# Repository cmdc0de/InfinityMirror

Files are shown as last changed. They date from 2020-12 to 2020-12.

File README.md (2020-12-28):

# InfinityMirror

## Materials you'll need:
* [Acrylic Mirror](https://www.amazon.com/Acrylic-Mirror-Sheet-Laser-Creations/dp/B01MXE417D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)
* [Acrylic see through Mirror](https://www.amazon.com/0-04-Acrylic-See-Through-Mirror-Transparent/dp/B07XTRC7F1?th=1)
* [ABS](https://www.raise3d.com/filaments/abs/) - I have a Raise 3D printer
* [22 Gauge Wire](https://www.amazon.com/gp/product/B00B4ZRPEY/ref=ppx_yo_dt_b_asin_title_o05_s02?ie=UTF8&psc=1)
* Solder 
* [Solder paste](https://www.amazon.com/Solder-Bi57-6-No-Clean-Lead-Free-Temperature/dp/B0195V1QEI/) - LOW TEMP solder
* Hot Glue
* [rechargable battery](https://www.amazon.com/Capacity-Rechargeable-Batteries-Flashlights-Headlamps/dp/B08MQDFQD4/)

## Equipment you'll need:
* 3d Printer
* laser cutter
* Solder Iron
* Hot Glue Gun

## Instructions
1. Mill/Etch/Order 20x Single-APA102c-breakout boards
2. Mill/Etch/Order 1x STM32G031J6M6 board
3. 3D Print: 3dprint/Base.stl, 3dprint/Base-bottom.stl, 3dprint/lid.stl, and 3dprint/octagon.stl
4. laser cut: laser-cutter/octagon v13.dxf 
5. Add components to the STM32G031J6M6 board.
6. Add componetns to 20x Single-APA102c-breakout boards - if you use an IR Oven make sure you use low temp solder!!! APA102c HATE 250 degress C!
7. Cut wires to length and connect all 20 Single-APA102c-breakout boards
8. Hot Glue apa102c breakouts into wholes of octogan - use a wire length of 3-4 inches for the first apa102c so you can feed it through the hole in the octagon and through the hole in the base to connect it to the STM32G031J6M6 baord.
9. Place acrylic mirror into bottom (it should fit via friction but I used a bit of CA glue as well).
10. place see through (2-way) mirror in the lid, again should fit via friction but I used a bit of CA glue as well.
11. Snap the lid on the octagon
12. Connect wires to STM32G031J6M6
13. Program the STM32G031J6M6 via J-LInk or ST-LInk connector and [STM32CubeIDE](https://www.st.com/en/development-tools/stm32cubeide.html)
  1. Open project in firmware directory
  2. compile and program 
14. Hot Glue board to bottom-lid such that the STM32G031J6M6 board fits in the whole in the base.
15. Connect a rechargable 3.7-5V battery to the screw terminals 
16. Connect Base-bottom to base

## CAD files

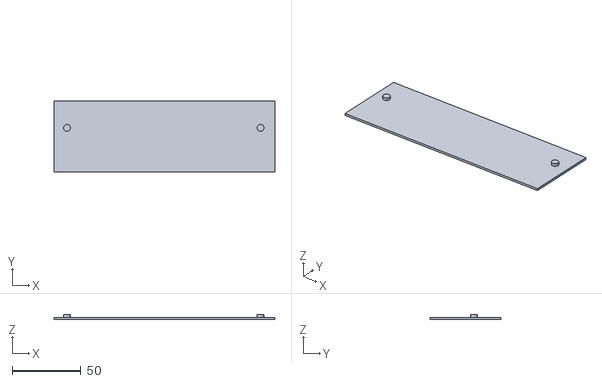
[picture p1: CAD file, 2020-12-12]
3d-print/base-bottom.stl
161.0 x 52.0 x 3.50

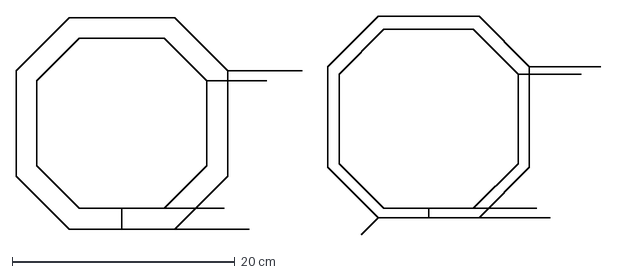
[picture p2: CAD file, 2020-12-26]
laser-cutter/octagon v13.dxf
52.4 x 19.6 cm

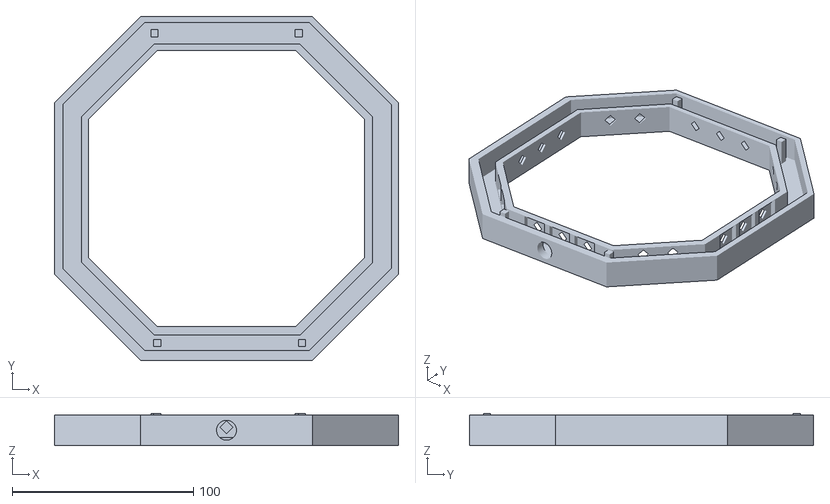
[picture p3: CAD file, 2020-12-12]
3d-print/octagon.stl
189.6 x 189.6 x 17.7

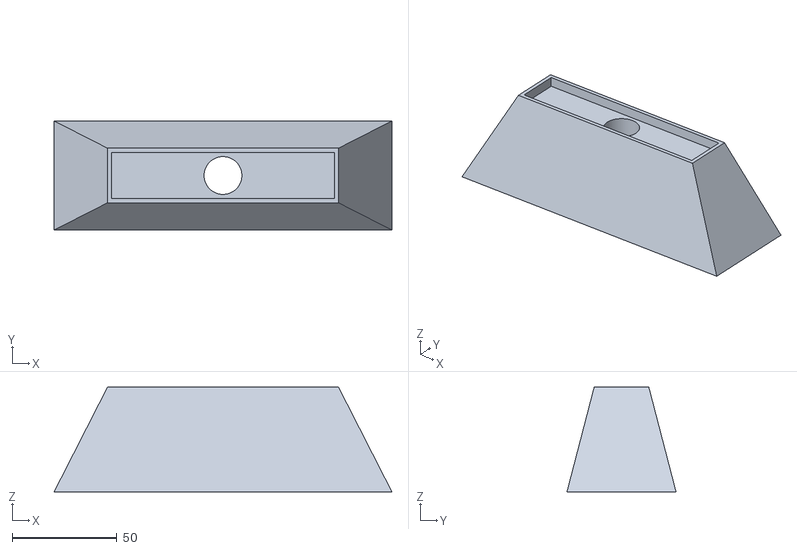
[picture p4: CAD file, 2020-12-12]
3d-print/base.stl
161.0 x 52.0 x 50.0

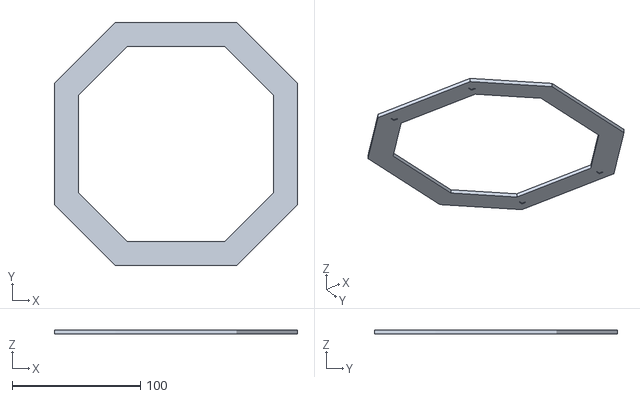
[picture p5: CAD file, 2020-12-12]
3d-print/lid.stl
189.6 x 189.6 x 3.10

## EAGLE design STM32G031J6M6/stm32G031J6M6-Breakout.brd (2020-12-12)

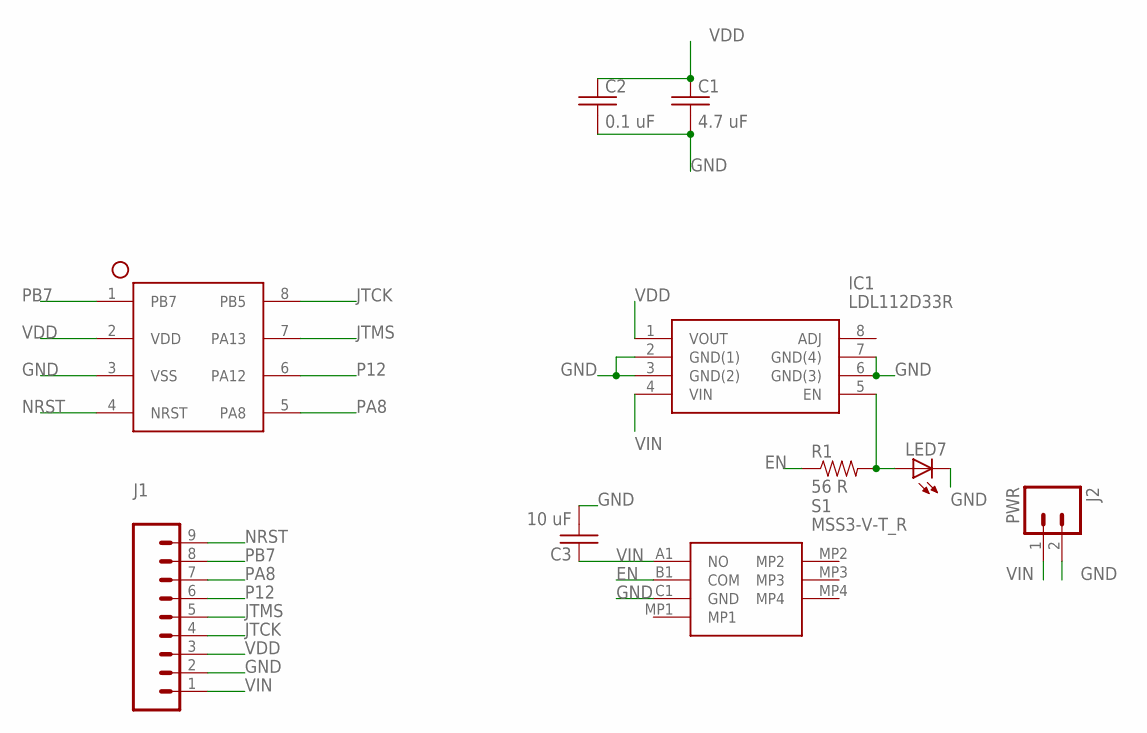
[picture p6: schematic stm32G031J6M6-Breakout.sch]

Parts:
C1: 4.7 uF; C0805K
C2: 0.1 uF; C0805K
C3: 10 uF; C0805K
IC1: LDL112D33R; SOIC127P600X175-8N
J1: M09LONGPADS; 1X09_LONGPADS
J2: PWR; SCREWTERMINAL-5MM-2
LED7: LED1206; LED-1206
R1: 56 R; 1206
S1: MSS3-V-T_R; MSS3VTR
U$1: STM32G031S08N; SOIC127P600X175-8N

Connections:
EN: R1.1, S1.B1 (COM)
GND: C1.2, C2.2, C3.2, IC1.2 (GND(1)), IC1.3 (GND(2)), IC1.6 (GND(3)), IC1.7 (GND(4)), J1.2, J2.2, LED7.C, S1.C1 (GND), U$1.3 (VSS)
JTCK: J1.4, U$1.8 (PB5)
JTMS: J1.5, U$1.7 (PA13)
unnamed: IC1.5 (EN), LED7.A, R1.2
NRST: J1.9, U$1.4 (NRST)
P12: J1.6, U$1.6 (PA12)
PA8: J1.7, U$1.5 (PA8)
PB7: J1.8, U$1.1 (PB7)
VDD: C1.1, C2.1, IC1.1 (VOUT), J1.3, U$1.2 (VDD)
VIN: C3.1, IC1.4 (VIN), J1.1, J2.1, S1.A1 (NO)

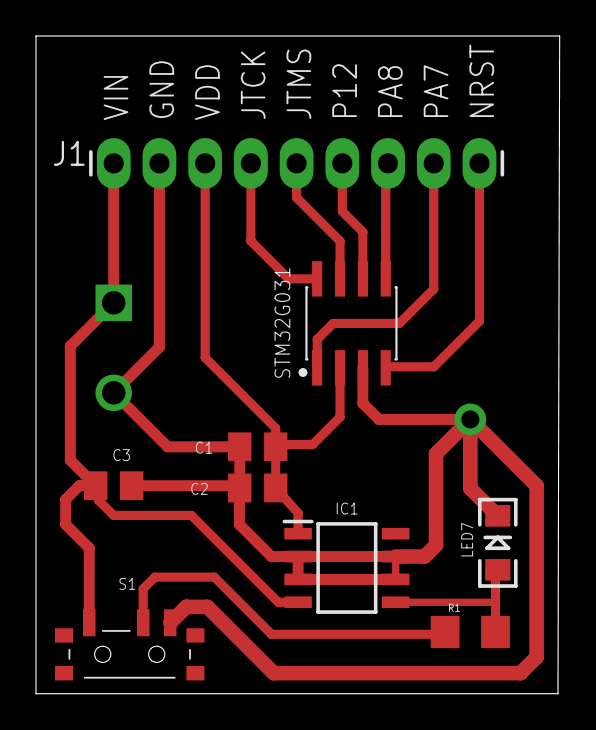
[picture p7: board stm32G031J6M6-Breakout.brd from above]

Board: 2 copper layers, 29.1 x 36.5 mm, 10 parts (1 on the bottom side), 11 nets.

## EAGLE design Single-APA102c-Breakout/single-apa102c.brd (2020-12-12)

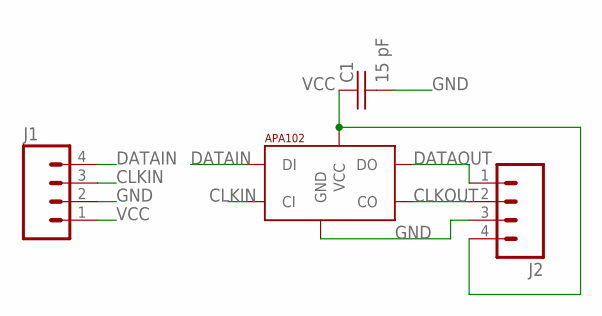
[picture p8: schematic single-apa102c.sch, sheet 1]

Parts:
C1: 15 pF; C0805K
J1, J2: M04PTH; 1X04
U$1: APA1025050; APA102_5050

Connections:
CLKIN: J1.3, U$1.5 (CI)
CLKOUT: J2.2, U$1.2 (CO)
DATAIN: J1.4, U$1.4 (DI)
DATAOUT: J2.1, U$1.3 (DO)
GND: C1.2, J1.2, J2.3, U$1.6 (GND)
VCC: C1.1, J1.1, J2.4, U$1.1 (VCC)

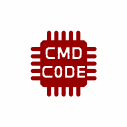
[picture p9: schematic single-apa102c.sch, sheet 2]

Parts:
U$2: CMD_C0DE_LOGOCMD_CODE_LOGO_SILK; CMD_C0DE_LOGO_SILK

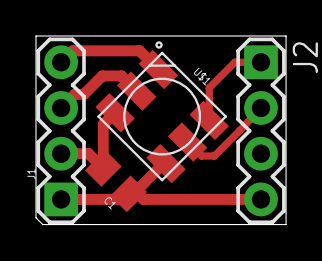
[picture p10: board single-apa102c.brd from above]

Board: 2 copper layers, 13.9 x 10.5 mm, 5 parts (1 on the bottom side), 6 nets.

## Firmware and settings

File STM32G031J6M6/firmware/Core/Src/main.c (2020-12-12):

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
/* Includes ------------------------------------------------------------------*/
#include "main.h"
#include "dma.h"
#include "spi.h"
#include "gpio.h"


void SystemClock_Config(void);
/**
  * @brief  The application entry point.
  * @retval int
  */
int main(void)
{
  /* MCU Configuration--------------------------------------------------------*/

  /* Reset of all peripherals, Initializes the Flash interface and the Systick. */
  HAL_Init();

  /* Configure the system clock */
  SystemClock_Config();

  /* Initialize all configured peripherals */
  MX_GPIO_Init();
  MX_DMA_Init();
  MX_SPI1_Init();
  /* USER CODE BEGIN 2 */
  static const uint32_t STORAGE=FLASH_PAGE_NB-1;
  uint32_t *startStorageAddress = STORAGE*FLASH_PAGE_SIZE+FLASH_BASE;
  if(((*startStorageAddress)&0xFF)==0xFF) {
	  if(HAL_OK!=HAL_FLASH_Program(FLASH_TYPEPROGRAM_DOUBLEWORD, startStorageAddress, 0x0000000000000000)) {
  			//blink LED
	  }
  } else if (((*startStorageAddress)&0xFF)==0x00) {
	  //search for first 0xFF, then move back 8 bytes and read value
  } else {
	  //error
  }
  //HAL_FLASH_Program(TypeProgram, Address, Data)

  /* USER CODE END 2 */

  /* Infinite loop */
  /* USER CODE BEGIN WHILE */
  while (1)
  {
    /* USER CODE END WHILE */

    /* USER CODE BEGIN 3 */
  }
  /* USER CODE END 3 */
}

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


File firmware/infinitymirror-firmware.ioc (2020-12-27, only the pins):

Mcu.UserName=STM32G031J6Mx
PA1.GPIO_Label=LED_CLK
PA1.Signal=SPI1_SCK
PA13.Signal=SYS_SWDIO
PA14-BOOT0.Signal=SYS_SWCLK
PB0.GPIO_Label=CHANGE_DANCE
PB0.Signal=GPIO_Input

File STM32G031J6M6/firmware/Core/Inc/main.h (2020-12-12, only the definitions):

#define BUTTON_IRQ_Pin GPIO_PIN_7
#define BUTTON_IRQ_GPIO_Port GPIOB
#define BUTTON_IRQ_EXTI_IRQn EXTI4_15_IRQn
#define INDICATOR_LED_Pin GPIO_PIN_11
#define INDICATOR_LED_GPIO_Port GPIOA

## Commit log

2020-11-21 initial checkin
    [single-apa102c.brd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]
2020-12-12 base code
    [single-apa102c.brd, single-apa102c.sch, stm32G031J6M6-Breakout.brd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]
2020-12-12 adding 3d print files
    [base-bottom.stl, base.stl, lid.stl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]
2020-12-26 adding new code but not working
    [octagon v13.dxf]

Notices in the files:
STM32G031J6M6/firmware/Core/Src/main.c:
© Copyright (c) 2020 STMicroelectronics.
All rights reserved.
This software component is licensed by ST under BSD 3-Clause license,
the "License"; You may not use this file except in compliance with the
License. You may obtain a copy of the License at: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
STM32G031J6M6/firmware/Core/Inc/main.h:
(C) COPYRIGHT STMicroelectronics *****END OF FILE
